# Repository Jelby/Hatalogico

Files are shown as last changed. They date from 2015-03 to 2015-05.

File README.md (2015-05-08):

##Hatalogico
Libraries for the Hatalogico Raspberry Pi Hat

###Cloning This Repo
When cloning, it is crucial that you use the --recursive switch in order to fetch the Adafruit submodules.

All the python files required to drive the I2C chips on the Hatalogico were written and are maintained by [Adafruit Industries](https://www.adafruit.com/). I have simply included them as submodules and written a few examples using them.

Before using these files, you need to setup your Pi for GPIO and I2C (note the Pi 2 has a slightly different method for the latter).

[Setting up the I2C](https://learn.adafruit.com/adafruits-raspberry-pi-lesson-4-gpio-setup/configuring-i2c)

[Setting up the GPIO](https://learn.adafruit.com/adafruits-raspberry-pi-lesson-4-gpio-setup/configuring-gpio)

##Installing
The RPi2 is slightly different but I recommend you 'apt-get' the following packages on both platforms:

**sudo apt-get update -y**  
**sudo apt-get install -y python-dev python-rpi.gpio python-smbus**  
**sudo apt-get install -y i2c-tools libi2c-dev**

You can copy and paste all 3 lines into your terminal and they will run one after the other (synchronously).

You will need to add the I2C tools to both versions:  
**sudo nano /etc/modules**

Scroll to the bottom and add:  
**i2c-dev**

####For RPi B+ and older only:
Also add a new line underneath 'i2c-dev':  
**i2c-bcm2708**

Crtl-X to close, pressing Y to save the changes (overwrite with the same name by pressing enter)

####For the RPi B+ or older you will need to update the blacklist file:  
**sudo nano /etc/modprobe.d/raspi-blacklist.conf**

Update it to read:  
\#blacklist spi-bcm2708  
\#blacklist i2c-bcm2708

After all of this, it's wise to do a little housekeeping (perhaps even removing some unused libraries):  
**sudo apt-get -y purge wolfram-engine**  
**sudo apt-get -y autoremove**  
**sudo apt-get -y clean**  
**sudo apt-get -y update**  
**sudo apt-get -y dist-upgrade**  

#I2C Addresses
(on the prototype model)

1. 16 Channel PWM: **0x70**
2. 4 Channel ADC #1: **0x49**
3. 4 Channel ADC #2: **0x48**
4. Single Channel DAC #1: **0x60**
5. Single Channel DAC #2: **0x61**

###Big thanks to Adafruit without whom the Hatalogico would just be a mug coaster.

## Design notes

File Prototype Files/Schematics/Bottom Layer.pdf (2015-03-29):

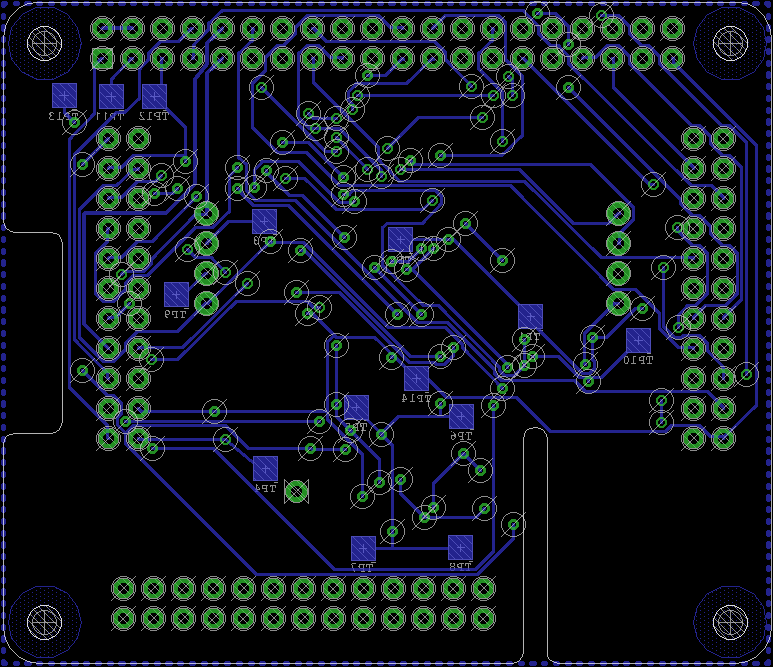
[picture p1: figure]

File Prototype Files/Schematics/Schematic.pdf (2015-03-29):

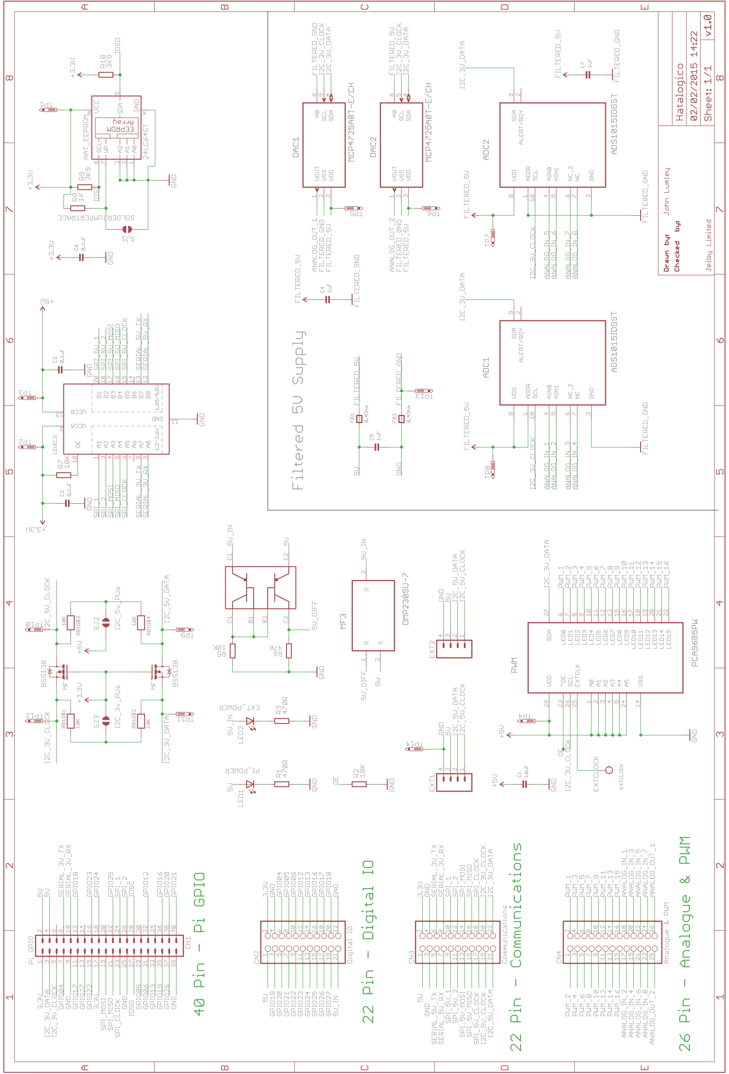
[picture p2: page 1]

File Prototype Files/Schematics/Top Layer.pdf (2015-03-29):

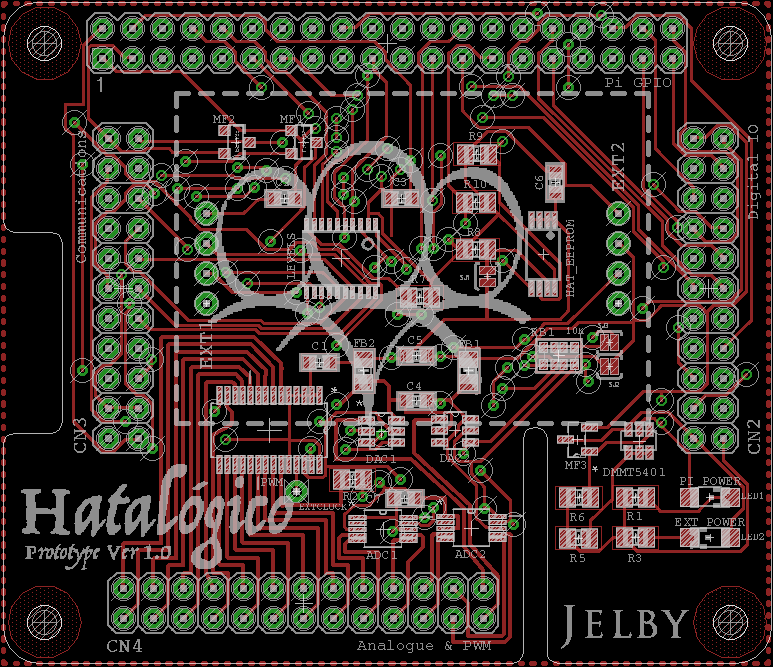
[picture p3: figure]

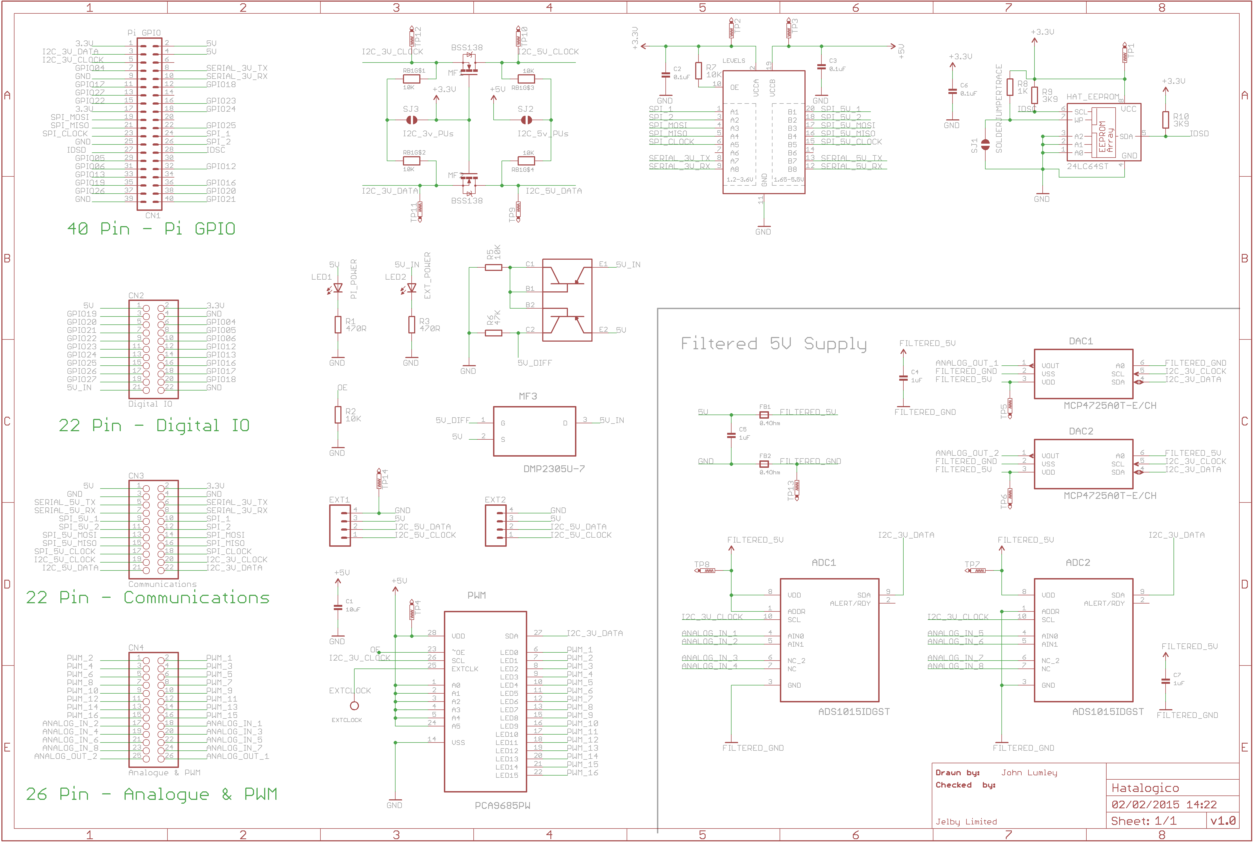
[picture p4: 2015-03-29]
Prototype Files/Schematics/Schematic.tif

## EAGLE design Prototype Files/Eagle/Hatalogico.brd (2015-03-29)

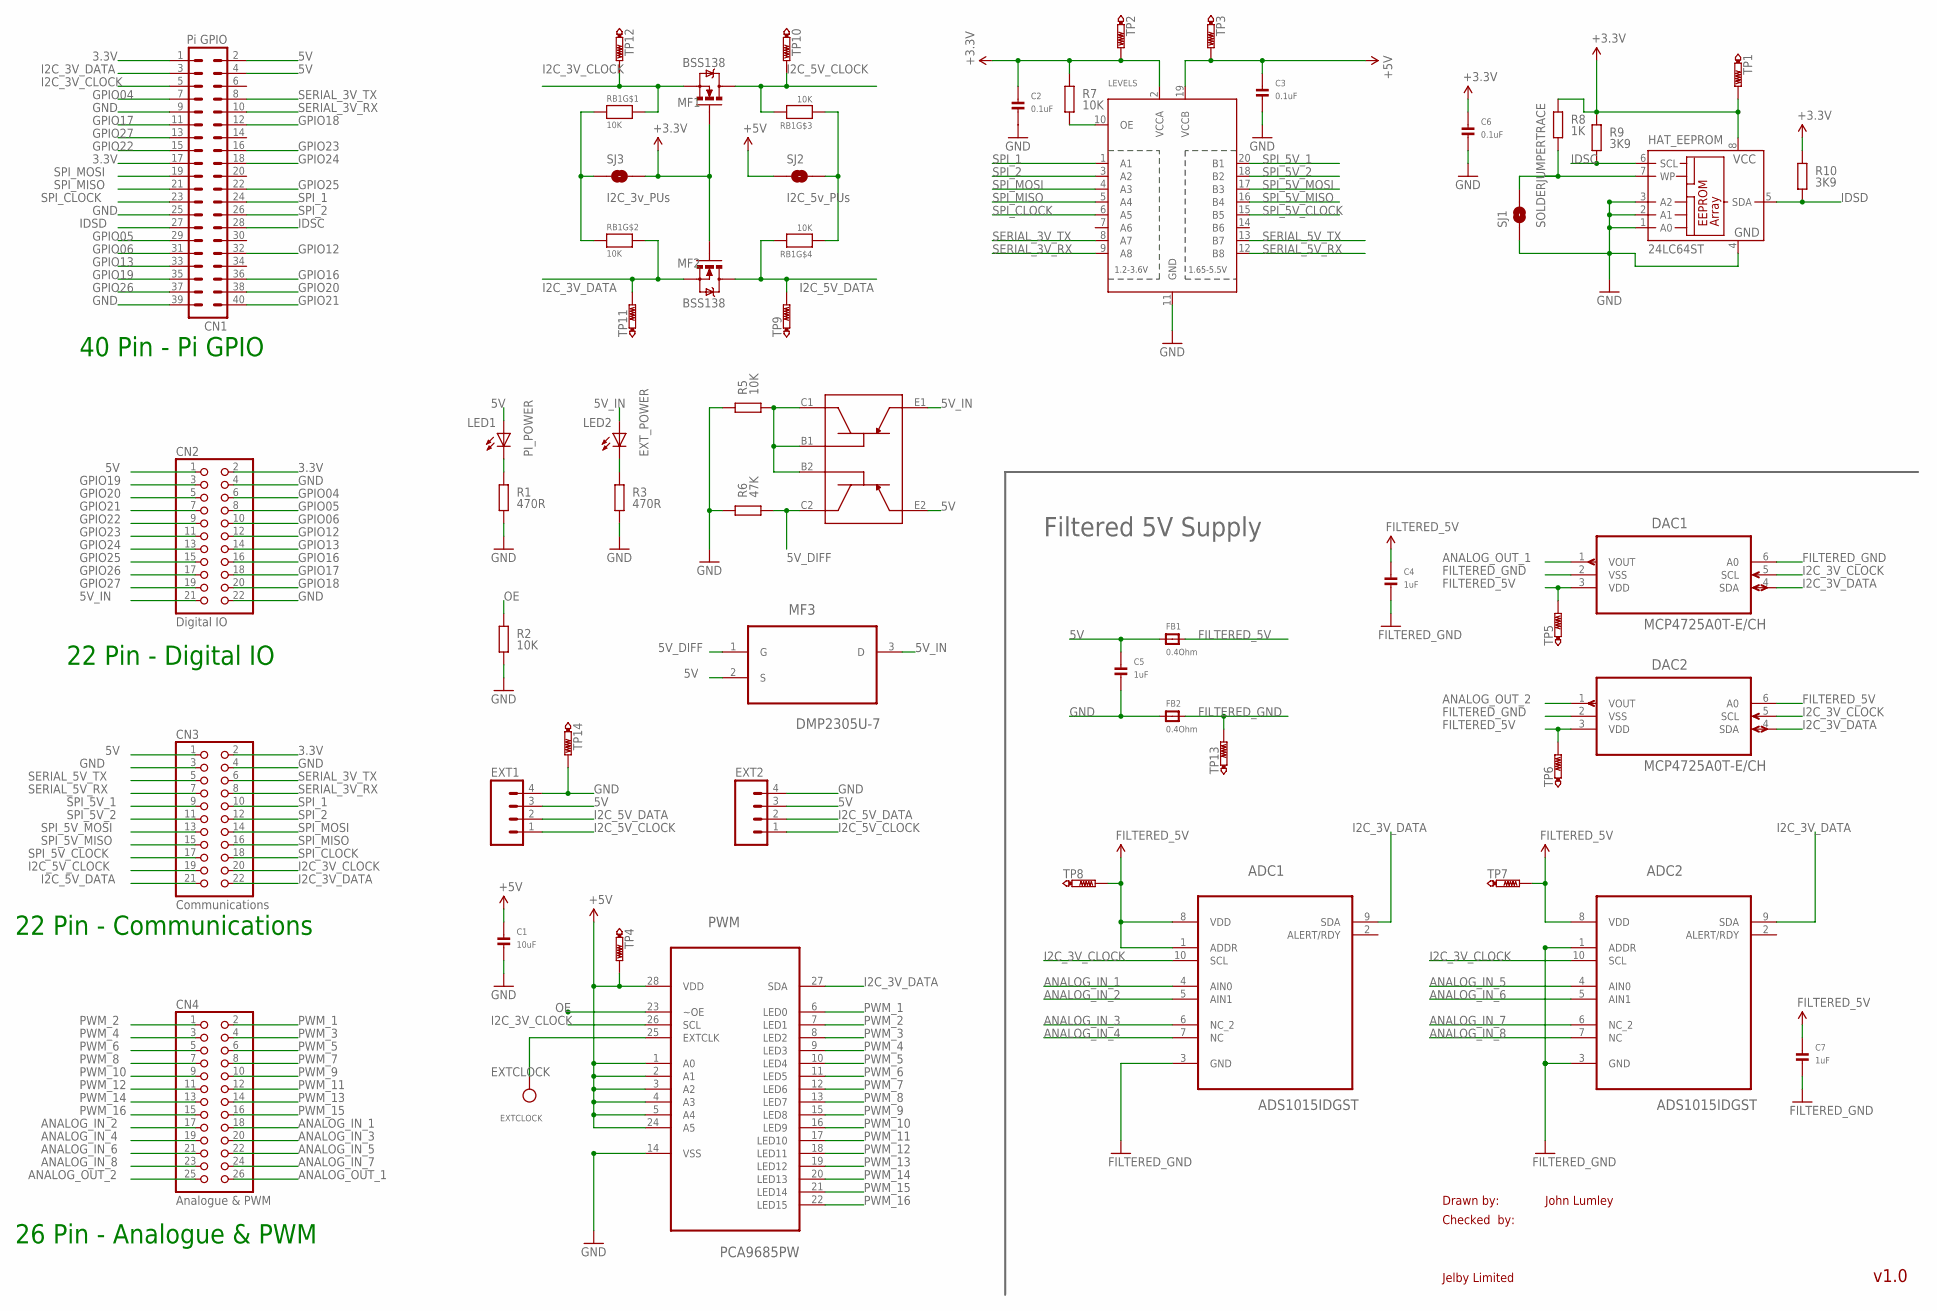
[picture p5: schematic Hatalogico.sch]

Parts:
ADC1, ADC2: ADS1015IDGST; SOP50P490X110-10N
C1: 10uF; 0603
C2, C3, C6: 0.1uF; 0603
C4, C5, C7: 1uF; 0603
CN1: Pi GPIO; PIN_20X2
CN2: Digital IO; 2X11
CN3: Communications; 2X11
CN4: Analogue & PWM; 2X13
DAC1, DAC2: MCP4725A0T-E/CH; SOT95P270X145-6N
EXT1, EXT2: 1X04_HEADER"; 1X04_HEADER
EXTCLOCK: TESTPOINT0.1"; 1X01_ROUND
FB1, FB2: 0.4Ohm; 0805
HAT_EEPROM: 24LC64ST; TSSOP8
LED1: PI_POWER; CHIPLED_1206
LED2: EXT_POWER; CHIPLED_1206
LEVELS: TXB0108PWR; TSSOP20
MF1, MF2: BSS138; SOT23-3
MF3: DMP2305U-7; SOT103P240X110-3N
PWM: PCA9685PW; SOP65P640X110-28N
R1, R3: 470R; M0805; TOLERANCE 5%
R2, R5, R7: 10K; M0805; TOLERANCE 5%
R6: 47K; M0805; TOLERANCE 5%
R8: 1K; M0805; TOLERANCE 5%
R9, R10: 3K9; M0805; TOLERANCE 5%
RB1: 10K; RESPACK_4X0603
SJ1: SOLDERJUMPERTRACE; SJ_2S-TRACE
SJ2: I2C_5v_PUs; PAD-JUMPER-2-NO_YES_SILK
SJ3: I2C_3v_PUs; PAD-JUMPER-2-NO_YES_SILK
T1: DMMT5401
TP1, TP2, TP3, TP4, TP5, TP6, TP7, TP8, TP9, TP10, TP11, TP12, TP13, TP14: PTR1TP20SQ; TP20SQ

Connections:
3.3V: C2.1, C6.1, CN1.1, CN1.17, CN2.2, CN3.2, HAT_EEPROM.8 (VCC), LEVELS.2 (VCCA), MF1.1 (G), MF2.1 (G), R7.2, R8.2, R9.2, R10.2, SJ3.2, TP1.TP, TP2.TP
5V: C1.1, C3.1, C5.1, CN1.2, CN1.4, CN2.1, CN3.1, EXT1.3, EXT2.3, FB1.1, LED1.A, LEVELS.19 (VCCB), MF3.2 (S), PWM.1 (A0), PWM.2 (A1), PWM.3 (A2), PWM.4 (A3), PWM.5 (A4), PWM.24 (A5), PWM.28 (VDD), SJ2.1, T1.E2, TP3.TP, TP4.TP
5V_DIFF: MF3.1 (G), R6.1, T1.C2
5V_IN: CN2.21, LED2.A, MF3.3 (D), T1.E1
ANALOG_IN_1: ADC1.4 (AIN0), CN4.18
ANALOG_IN_2: ADC1.5 (AIN1), CN4.17
ANALOG_IN_3: ADC1.6 (NC_2), CN4.20
ANALOG_IN_4: ADC1.7 (NC), CN4.19
ANALOG_IN_5: ADC2.4 (AIN0), CN4.22
ANALOG_IN_6: ADC2.5 (AIN1), CN4.21
ANALOG_IN_7: ADC2.6 (NC_2), CN4.24
ANALOG_IN_8: ADC2.7 (NC), CN4.23
ANALOG_OUT_1: CN4.26, DAC1.1 (VOUT)
ANALOG_OUT_2: CN4.25, DAC2.1 (VOUT)
EXTCLOCK: EXTCLOCK.1, PWM.25 (EXTCLK)
FILTERED_5V: ADC1.1 (ADDR), ADC1.8 (VDD), ADC2.8 (VDD), C4.1, C7.1, DAC1.3 (VDD), DAC2.3 (VDD), DAC2.6 (A0), FB1.2, TP5.TP, TP6.TP, TP7.TP, TP8.TP
FILTERED_GND: ADC1.3 (GND), ADC2.1 (ADDR), ADC2.3 (GND), C4.2, C7.2, DAC1.2 (VSS), DAC1.6 (A0), DAC2.2 (VSS), FB2.2, TP13.TP
GND: C1.2, C2.2, C3.2, C5.2, C6.2, CN1.9, CN1.25, CN1.39, CN2.4, CN2.22, CN3.3, CN3.4, EXT1.4, EXT2.4, FB2.1, HAT_EEPROM.1 (A0), HAT_EEPROM.2 (A1), HAT_EEPROM.3 (A2), HAT_EEPROM.4 (GND), LEVELS.11 (GND), PWM.14 (VSS), R1.1, R2.1, R3.1, R5.2, R6.2, SJ1.1, TP14.TP
GPIO04: CN1.7, CN2.6
GPIO05: CN1.29, CN2.8
GPIO06: CN1.31, CN2.10
GPIO12: CN1.32, CN2.12
GPIO13: CN1.33, CN2.14
GPIO16: CN1.36, CN2.16
GPIO17: CN1.11, CN2.18
GPIO18: CN1.12, CN2.20
GPIO19: CN1.35, CN2.3
GPIO20: CN1.38, CN2.5
GPIO21: CN1.40, CN2.7
GPIO22: CN1.15, CN2.9
GPIO23: CN1.16, CN2.11
GPIO24: CN1.18, CN2.13
GPIO25: CN1.22, CN2.15
GPIO26: CN1.37, CN2.17
GPIO27: CN1.13, CN2.19
I2C_3V_CLOCK: ADC1.10 (SCL), ADC2.10 (SCL), CN1.5, CN3.20, DAC1.5 (SCL), DAC2.5 (SCL), MF1.2 (S), PWM.26 (SCL), RB1.8 (2), TP12.TP
I2C_3V_DATA: ADC1.9 (SDA), ADC2.9 (SDA), CN1.3, CN3.22, DAC1.4 (SDA), DAC2.4 (SDA), MF2.2 (S), PWM.27 (SDA), RB1.7 (2), TP11.TP
I2C_5V_CLOCK: CN3.19, EXT1.1, EXT2.1, MF1.3 (D), RB1.6 (2), TP10.TP
I2C_5V_DATA: CN3.21, EXT1.2, EXT2.2, MF2.3 (D), RB1.5 (2), TP9.TP
IDSC: CN1.28, HAT_EEPROM.6 (SCL), R9.1
IDSD: CN1.27, HAT_EEPROM.5 (SDA), R10.1
LEDOUT: LED1.C, R1.2
LEDOUT1: LED2.C, R3.2
unnamed: R5.1, T1.B1, T1.B2, T1.C1
unnamed: RB1.1, RB1.2 (1), SJ3.1
unnamed: RB1.3 (1), RB1.4 (1), SJ2.2
unnamed: LEVELS.10 (OE), R7.1
OE: PWM.23 (~OE), R2.2
PWM_1: CN4.2, PWM.6 (LED0)
PWM_2: CN4.1, PWM.7 (LED1)
PWM_3: CN4.4, PWM.8 (LED2)
PWM_4: CN4.3, PWM.9 (LED3)
PWM_5: CN4.6, PWM.10 (LED4)
PWM_6: CN4.5, PWM.11 (LED5)
PWM_7: CN4.8, PWM.12 (LED6)
PWM_8: CN4.7, PWM.13 (LED7)
PWM_9: CN4.10, PWM.15 (LED8)
PWM_10: CN4.9, PWM.16 (LED9)
PWM_11: CN4.12, PWM.17 (LED10)
PWM_12: CN4.11, PWM.18 (LED11)
PWM_13: CN4.14, PWM.19 (LED12)
PWM_14: CN4.13, PWM.20 (LED13)
PWM_15: CN4.16, PWM.21 (LED14)
PWM_16: CN4.15, PWM.22 (LED15)
SERIAL_3V_RX: CN1.10, CN3.8, LEVELS.9 (A8)
SERIAL_3V_TX: CN1.8, CN3.6, LEVELS.8 (A7)
SERIAL_5V_RX: CN3.7, LEVELS.12 (B8)
SERIAL_5V_TX: CN3.5, LEVELS.13 (B7)
SPI_1: CN1.24, CN3.10, LEVELS.1 (A1)
SPI_2: CN1.26, CN3.12, LEVELS.3 (A2)
SPI_5V_1: CN3.9, LEVELS.20 (B1)
SPI_5V_2: CN3.11, LEVELS.18 (B2)
SPI_5V_CLOCK: CN3.17, LEVELS.15 (B5)
SPI_5V_MISO: CN3.15, LEVELS.16 (B4)
SPI_5V_MOSI: CN3.13, LEVELS.17 (B3)
SPI_CLOCK: CN1.23, CN3.18, LEVELS.6 (A5)
SPI_MISO: CN1.21, CN3.16, LEVELS.5 (A4)
SPI_MOSI: CN1.19, CN3.14, LEVELS.4 (A3)
WP: HAT_EEPROM.7 (WP), R8.1, SJ1.2

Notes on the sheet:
Drawn by:
Checked by:
Jelby Limited
John Lumley
v1.0
40 Pin - Pi GPIO
26 Pin - Analogue & PWM
22 Pin - Digital IO
22 Pin - Communications
Filtered 5V Supply

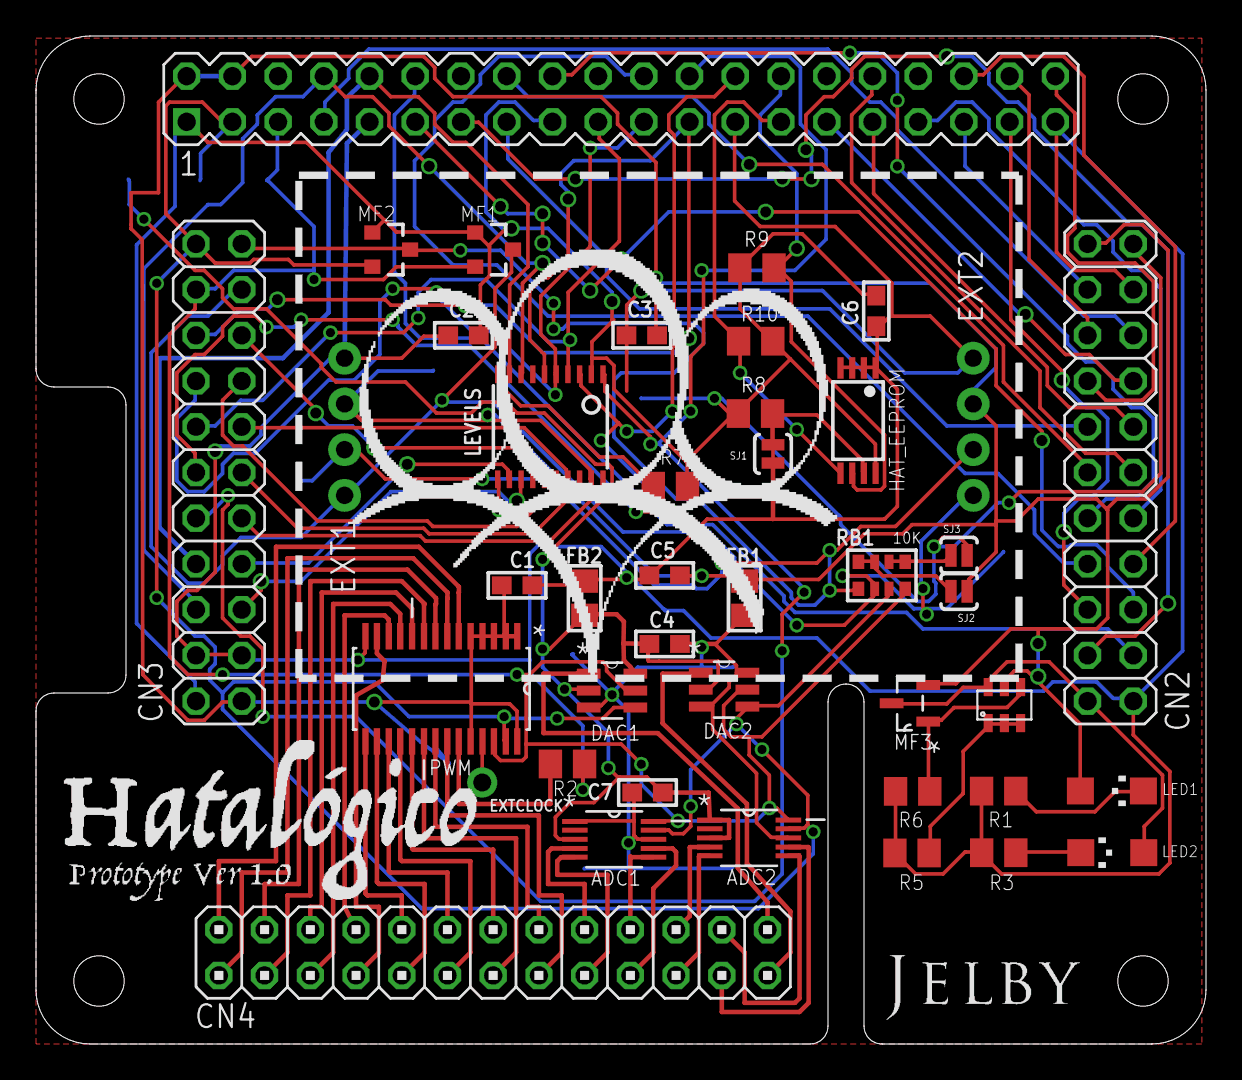
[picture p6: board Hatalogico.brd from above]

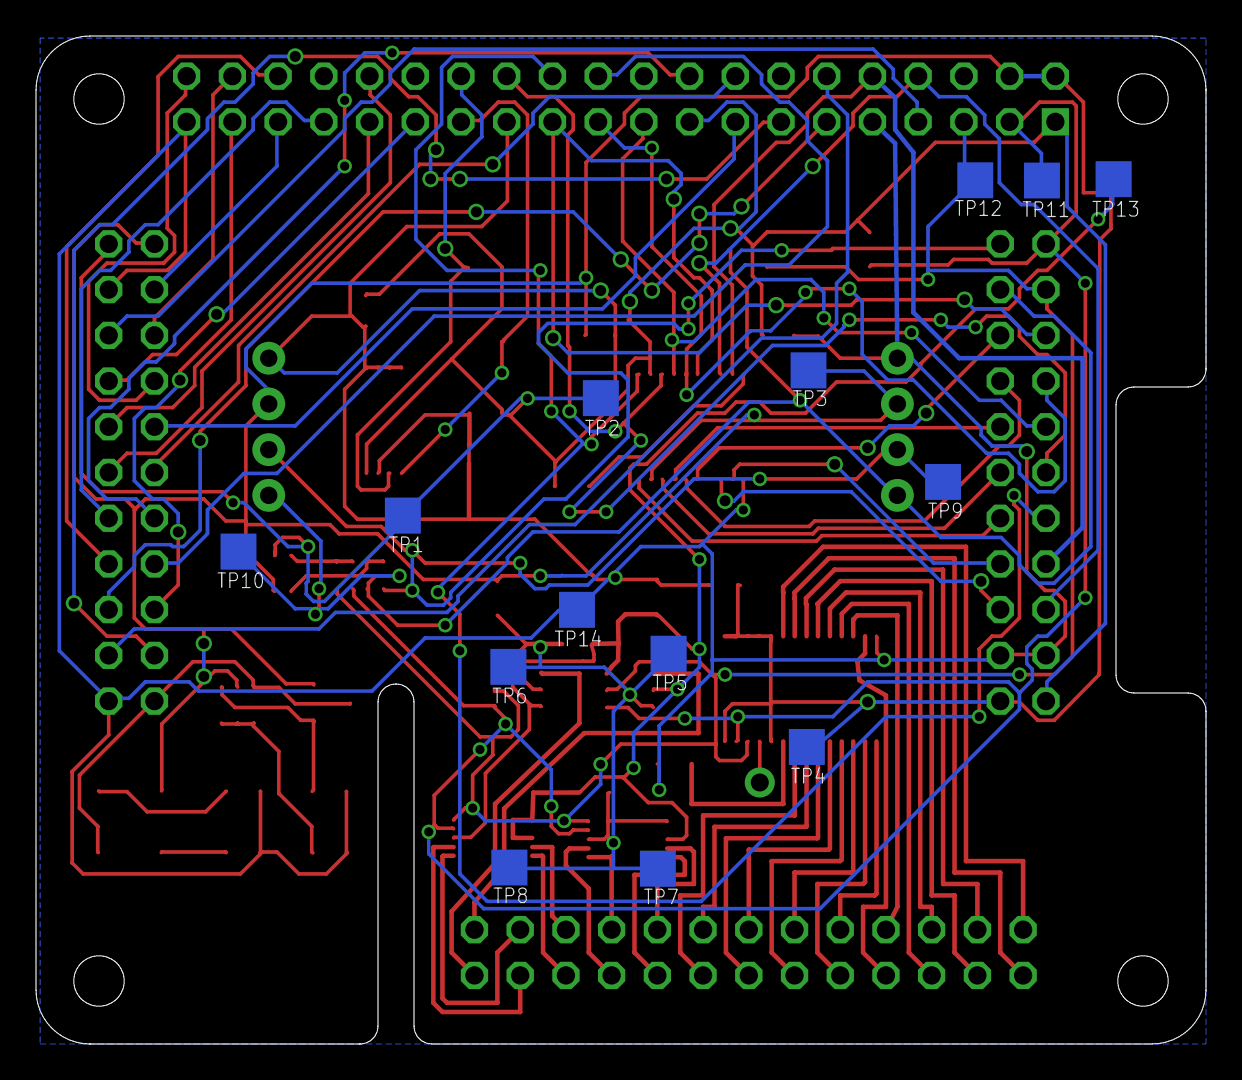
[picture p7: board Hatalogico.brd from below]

Board: 2 copper layers, 65.0 x 56.0 mm, 56 parts (14 on the bottom side), 79 nets.

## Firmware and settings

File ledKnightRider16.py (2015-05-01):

#!/usr/bin/python

# ===========================================================================
# Hatalogico KNIGHT RIDER for 8 LEDs - powered by Adafruit's Libraries
# -------------------------------------------------
# Date: 12/4/2015
# Author: John Lumley
#
# BIG THANKS TO ADAFRUIT INDUSTRIES FOR MAKING THIS POSSIBLE AND EASY
# ===========================================================================

import time, os, sys

# DETERMINE CURRENT PATH
scriptPath = os.path.realpath(os.path.dirname(sys.argv[0]))
os.chdir(scriptPath)
# APPEND FOLDER OF REQUIRED LIBRARY
sys.path.append("Adafruit/Adafruit_PWM_Servo_Driver")
# FINALLY LOAD THE LIBRARY
from Adafruit_PWM_Servo_Driver import PWM

LED_PIN_0 = 0
LED_PIN_1 = 2
LED_PIN_2 = 4
LED_PIN_3 = 6
LED_PIN_4 = 8
LED_PIN_5 = 10
LED_PIN_6 = 12
LED_PIN_7 = 14
LED_PIN_8 = 1
LED_PIN_9 = 3
LED_PIN_10 = 5
LED_PIN_11 = 7
LED_PIN_12 = 9
LED_PIN_13 = 11
LED_PIN_14 = 13
LED_PIN_15 = 15

BRIGHT_0=0
BRIGHT_1=1800
BRIGHT_2=2400
BRIGHT_3=3000
BRIGHT_4=3500
BRIGHT_5=3800
BRIGHT_6=4000
BRIGHT_7=4095

# BUILD 16 ARRAYS OF 8 POSITIONS/VALUES FOR PWM LOOP
position = {} 
position[0] = [ BRIGHT_0, BRIGHT_7, BRIGHT_7, BRIGHT_7, BRIGHT_7, BRIGHT_7, BRIGHT_7, BRIGHT_7, BRIGHT_7, BRIGHT_7, BRIGHT_7, BRIGHT_7, BRIGHT_7, BRIGHT_7, BRIGHT_7, BRIGHT_7 ]
position[1] = [ BRIGHT_1, BRIGHT_0, BRIGHT_7, BRIGHT_7, BRIGHT_7, BRIGHT_7, BRIGHT_7, BRIGHT_7, BRIGHT_7, BRIGHT_7, BRIGHT_7, BRIGHT_7, BRIGHT_7, BRIGHT_7, BRIGHT_7, BRIGHT_7 ]
position[2] = [ BRIGHT_2, BRIGHT_1, BRIGHT_0, BRIGHT_7, BRIGHT_7, BRIGHT_7, BRIGHT_7, BRIGHT_7, BRIGHT_7, BRIGHT_7, BRIGHT_7, BRIGHT_7, BRIGHT_7, BRIGHT_7, BRIGHT_7, BRIGHT_7 ]
position[3] = [ BRIGHT_3, BRIGHT_2, BRIGHT_1, BRIGHT_0, BRIGHT_7, BRIGHT_7, BRIGHT_7, BRIGHT_7, BRIGHT_7, BRIGHT_7, BRIGHT_7, BRIGHT_7, BRIGHT_7, BRIGHT_7, BRIGHT_7, BRIGHT_7 ]
position[4] = [ BRIGHT_4, BRIGHT_3, BRIGHT_2, BRIGHT_1, BRIGHT_0, BRIGHT_7, BRIGHT_7, BRIGHT_7, BRIGHT_7, BRIGHT_7, BRIGHT_7, BRIGHT_7, BRIGHT_7, BRIGHT_7, BRIGHT_7, BRIGHT_7 ]
position[5] = [ BRIGHT_5, BRIGHT_4, BRIGHT_3, BRIGHT_2, BRIGHT_1, BRIGHT_0, BRIGHT_7, BRIGHT_7, BRIGHT_7, BRIGHT_7, BRIGHT_7, BRIGHT_7, BRIGHT_7, BRIGHT_7, BRIGHT_7, BRIGHT_7 ]
position[6] = [ BRIGHT_6, BRIGHT_5, BRIGHT_4, BRIGHT_3, BRIGHT_2, BRIGHT_1, BRIGHT_0, BRIGHT_7, BRIGHT_7, BRIGHT_7, BRIGHT_7, BRIGHT_7, BRIGHT_7, BRIGHT_7, BRIGHT_7, BRIGHT_7 ]
position[7] = [ BRIGHT_7, BRIGHT_6, BRIGHT_5, BRIGHT_4, BRIGHT_3, BRIGHT_2, BRIGHT_1, BRIGHT_0, BRIGHT_7, BRIGHT_7, BRIGHT_7, BRIGHT_7, BRIGHT_7, BRIGHT_7, BRIGHT_7, BRIGHT_7 ]
position[8] = [ BRIGHT_7, BRIGHT_7, BRIGHT_6, BRIGHT_5, BRIGHT_4, BRIGHT_3, BRIGHT_2, BRIGHT_1, BRIGHT_0, BRIGHT_7, BRIGHT_7, BRIGHT_7, BRIGHT_7, BRIGHT_7, BRIGHT_7, BRIGHT_7 ]
position[9] = [ BRIGHT_7, BRIGHT_7, BRIGHT_7, BRIGHT_6, BRIGHT_5, BRIGHT_4, BRIGHT_3, BRIGHT_2, BRIGHT_1, BRIGHT_0, BRIGHT_7, BRIGHT_7, BRIGHT_7, BRIGHT_7, BRIGHT_7, BRIGHT_7 ]
position[10] = [ BRIGHT_7, BRIGHT_7, BRIGHT_7, BRIGHT_7, BRIGHT_6, BRIGHT_5, BRIGHT_4, BRIGHT_3, BRIGHT_2, BRIGHT_1, BRIGHT_0, BRIGHT_7, BRIGHT_7, BRIGHT_7, BRIGHT_7, BRIGHT_7 ]
position[11] = [ BRIGHT_7, BRIGHT_7, BRIGHT_7, BRIGHT_7, BRIGHT_7, BRIGHT_6, BRIGHT_5, BRIGHT_4, BRIGHT_3, BRIGHT_2, BRIGHT_1, BRIGHT_0, BRIGHT_7, BRIGHT_7, BRIGHT_7, BRIGHT_7 ]
position[12] = [ BRIGHT_7, BRIGHT_7, BRIGHT_7, BRIGHT_7, BRIGHT_7, BRIGHT_7, BRIGHT_6, BRIGHT_5, BRIGHT_4, BRIGHT_3, BRIGHT_2, BRIGHT_1, BRIGHT_0, BRIGHT_7, BRIGHT_7, BRIGHT_7 ]
position[13] = [ BRIGHT_7, BRIGHT_7, BRIGHT_7, BRIGHT_7, BRIGHT_7, BRIGHT_7, BRIGHT_7, BRIGHT_6, BRIGHT_5, BRIGHT_4, BRIGHT_3, BRIGHT_2, BRIGHT_1, BRIGHT_0, BRIGHT_7, BRIGHT_7 ]
position[14] = [ BRIGHT_7, BRIGHT_7, BRIGHT_7, BRIGHT_7, BRIGHT_7, BRIGHT_7, BRIGHT_7, BRIGHT_7, BRIGHT_6, BRIGHT_5, BRIGHT_4, BRIGHT_3, BRIGHT_2, BRIGHT_1, BRIGHT_0, BRIGHT_7 ]
position[15] = [ BRIGHT_7, BRIGHT_7, BRIGHT_7, BRIGHT_7, BRIGHT_7, BRIGHT_7, BRIGHT_7, BRIGHT_7, BRIGHT_7, BRIGHT_6, BRIGHT_5, BRIGHT_4, BRIGHT_3, BRIGHT_2, BRIGHT_1, BRIGHT_0 ]
position[16] = [ BRIGHT_7, BRIGHT_7, BRIGHT_7, BRIGHT_7, BRIGHT_7, BRIGHT_7, BRIGHT_7, BRIGHT_7, BRIGHT_7, BRIGHT_7, BRIGHT_6, BRIGHT_5, BRIGHT_4, BRIGHT_3, BRIGHT_2, BRIGHT_0 ]
position[17] = [ BRIGHT_7, BRIGHT_7, BRIGHT_7, BRIGHT_7, BRIGHT_7, BRIGHT_7, BRIGHT_7, BRIGHT_7, BRIGHT_7, BRIGHT_7, BRIGHT_7, BRIGHT_6, BRIGHT_5, BRIGHT_4, BRIGHT_3, BRIGHT_0 ]
position[18] = [ BRIGHT_7, BRIGHT_7, BRIGHT_7, BRIGHT_7, BRIGHT_7, BRIGHT_7, BRIGHT_7, BRIGHT_7, BRIGHT_7, BRIGHT_7, BRIGHT_7, BRIGHT_7, BRIGHT_6, BRIGHT_5, BRIGHT_4, BRIGHT_0 ]
position[19] = [ BRIGHT_7, BRIGHT_7, BRIGHT_7, BRIGHT_7, BRIGHT_7, BRIGHT_7, BRIGHT_7, BRIGHT_7, BRIGHT_7, BRIGHT_7, BRIGHT_7, BRIGHT_7, BRIGHT_7, BRIGHT_6, BRIGHT_5, BRIGHT_0 ]
position[20] = [ BRIGHT_7, BRIGHT_7, BRIGHT_7, BRIGHT_7, BRIGHT_7, BRIGHT_7, BRIGHT_7, BRIGHT_7, BRIGHT_7, BRIGHT_7, BRIGHT_7, BRIGHT_7, BRIGHT_7, BRIGHT_7, BRIGHT_6, BRIGHT_0 ]
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

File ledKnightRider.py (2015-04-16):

#!/usr/bin/python

# ===========================================================================
# Hatalogico KNIGHT RIDER for 8 LEDs - powered by Adafruit's Libraries
# -------------------------------------------------
# Date: 12/4/2015
# Author: John Lumley
#
# BIG THANKS TO ADAFRUIT INDUSTRIES FOR MAKING THIS POSSIBLE AND EASY
# ===========================================================================

import time, os, sys

# DETERMINE CURRENT PATH
scriptPath = os.path.realpath(os.path.dirname(sys.argv[0]))
os.chdir(scriptPath)
# APPEND FOLDER OF REQUIRED LIBRARY
sys.path.append("Adafruit/Adafruit_PWM_Servo_Driver")
# FINALLY LOAD THE LIBRARY
from Adafruit_PWM_Servo_Driver import PWM

LED_PIN_0 = 1
LED_PIN_1 = 3
LED_PIN_2 = 5
LED_PIN_3 = 7
LED_PIN_4 = 9
LED_PIN_5 = 11
LED_PIN_6 = 13
LED_PIN_7 = 15

BRIGHT_STEP_0=0
BRIGHT_STEP_1=2048
BRIGHT_STEP_2=3070
BRIGHT_STEP_3=3500
BRIGHT_STEP_4=3800
BRIGHT_STEP_5=4048
BRIGHT_STEP_6=4095
BRIGHT_STEP_7=4095

# BUILD 16 ARRAYS OF 8 POSITIONS/VALUES FOR PWM LOOP
position = {} 
position[0] = [ BRIGHT_STEP_0, BRIGHT_STEP_5, BRIGHT_STEP_6, BRIGHT_STEP_7, BRIGHT_STEP_7, BRIGHT_STEP_7, BRIGHT_STEP_7, BRIGHT_STEP_7 ]
position[1] = [ BRIGHT_STEP_0, BRIGHT_STEP_4, BRIGHT_STEP_5, BRIGHT_STEP_6, BRIGHT_STEP_7, BRIGHT_STEP_7, BRIGHT_STEP_7, BRIGHT_STEP_7 ]
position[2] = [ BRIGHT_STEP_0, BRIGHT_STEP_3, BRIGHT_STEP_4, BRIGHT_STEP_5, BRIGHT_STEP_6, BRIGHT_STEP_7, BRIGHT_STEP_7, BRIGHT_STEP_7 ]
position[3] = [ BRIGHT_STEP_0, BRIGHT_STEP_2, BRIGHT_STEP_3, BRIGHT_STEP_4, BRIGHT_STEP_5, BRIGHT_STEP_6, BRIGHT_STEP_7, BRIGHT_STEP_7 ]
position[4] = [ BRIGHT_STEP_0, BRIGHT_STEP_1, BRIGHT_STEP_2, BRIGHT_STEP_3, BRIGHT_STEP_4, BRIGHT_STEP_5, BRIGHT_STEP_6, BRIGHT_STEP_7 ]
position[5] = [ BRIGHT_STEP_1, BRIGHT_STEP_0, BRIGHT_STEP_1, BRIGHT_STEP_2, BRIGHT_STEP_3, BRIGHT_STEP_4, BRIGHT_STEP_5, BRIGHT_STEP_6 ]
position[6] = [ BRIGHT_STEP_2, BRIGHT_STEP_1, BRIGHT_STEP_0, BRIGHT_STEP_1, BRIGHT_STEP_2, BRIGHT_STEP_3, BRIGHT_STEP_4, BRIGHT_STEP_5 ]
position[7] = [ BRIGHT_STEP_3, BRIGHT_STEP_2, BRIGHT_STEP_1, BRIGHT_STEP_0, BRIGHT_STEP_1, BRIGHT_STEP_2, BRIGHT_STEP_3, BRIGHT_STEP_4 ]
position[8] = [ BRIGHT_STEP_4, BRIGHT_STEP_3, BRIGHT_STEP_2, BRIGHT_STEP_1, BRIGHT_STEP_0, BRIGHT_STEP_1, BRIGHT_STEP_2, BRIGHT_STEP_3 ]
position[9] = [ BRIGHT_STEP_5, BRIGHT_STEP_4, BRIGHT_STEP_3, BRIGHT_STEP_2, BRIGHT_STEP_1, BRIGHT_STEP_0, BRIGHT_STEP_1, BRIGHT_STEP_2 ]
position[10] = [ BRIGHT_STEP_6, BRIGHT_STEP_5, BRIGHT_STEP_4, BRIGHT_STEP_3, BRIGHT_STEP_2, BRIGHT_STEP_1, BRIGHT_STEP_0, BRIGHT_STEP_1 ]
position[11] = [ BRIGHT_STEP_7, BRIGHT_STEP_6, BRIGHT_STEP_5, BRIGHT_STEP_4, BRIGHT_STEP_3, BRIGHT_STEP_2, BRIGHT_STEP_1, BRIGHT_STEP_0 ]
position[12] = [ BRIGHT_STEP_7, BRIGHT_STEP_7, BRIGHT_STEP_6, BRIGHT_STEP_5, BRIGHT_STEP_4, BRIGHT_STEP_3, BRIGHT_STEP_2, BRIGHT_STEP_0 ]
position[13] = [ BRIGHT_STEP_7, BRIGHT_STEP_7, BRIGHT_STEP_7, BRIGHT_STEP_6, BRIGHT_STEP_5, BRIGHT_STEP_4, BRIGHT_STEP_3, BRIGHT_STEP_0 ]
position[14] = [ BRIGHT_STEP_7, BRIGHT_STEP_7, BRIGHT_STEP_7, BRIGHT_STEP_7, BRIGHT_STEP_6, BRIGHT_STEP_5, BRIGHT_STEP_4, BRIGHT_STEP_0 ]
position[15] = [ BRIGHT_STEP_7, BRIGHT_STEP_7, BRIGHT_STEP_7, BRIGHT_STEP_7, BRIGHT_STEP_7, BRIGHT_STEP_6, BRIGHT_STEP_5, BRIGHT_STEP_0 ]

# SETUP THE PWM DRIVER (I2C ADDRESS IS 70 BY DEFAULT ON HATALOGICO)
# EACH CHANNEL RANGES FROM 0 (off) TO 4095 (on)
pwm = PWM(0x70)
# SET FREQUENCY
pwm.setPWMFreq(120)

while (True):
	for posNo in range(0, 16, +1):
		pwm.setPWM(LED_PIN_0, 0, position[ posNo ][0])
		pwm.setPWM(LED_PIN_1, 0, position[ posNo ][1])
		pwm.setPWM(LED_PIN_2, 0, position[ posNo ][2])
		pwm.setPWM(LED_PIN_3, 0, position[ posNo ][3])
		pwm.setPWM(LED_PIN_4, 0, position[ posNo ][4])
		pwm.setPWM(LED_PIN_5, 0, position[ posNo ][5])
		pwm.setPWM(LED_PIN_6, 0, position[ posNo ][6])
		pwm.setPWM(LED_PIN_7, 0, position[ posNo ][7])
		
		# HAVE A LITTLE NAP
		time.sleep(0.05)

	for posNo in range(15, -1, -1):
		pwm.setPWM(LED_PIN_0, 0, position[ posNo ][0])
		pwm.setPWM(LED_PIN_1, 0, position[ posNo ][1])
		pwm.setPWM(LED_PIN_2, 0, position[ posNo ][2])
		pwm.setPWM(LED_PIN_3, 0, position[ posNo ][3])
		pwm.setPWM(LED_PIN_4, 0, position[ posNo ][4])
		pwm.setPWM(LED_PIN_5, 0, position[ posNo ][5])
		pwm.setPWM(LED_PIN_6, 0, position[ posNo ][6])
		pwm.setPWM(LED_PIN_7, 0, position[ posNo ][7])
		
		# HAVE A LITTLE NAP
		time.sleep(0.05)

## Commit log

2015-03-22 Adding first examples
    LED PWM example
    DAC to ADC example
2015-03-24 Updating LED examples
    And a startup test script
2015-03-24 Adding I2C addesses
2015-03-29 Schematics and design files
    [Hatalogico.brd, Hatalogico.sch]
2015-04-12 Random LED timing tweak
2015-04-13 Reverse KR brightnesses for sinking not sourcing
    [ledKnightRider.py]

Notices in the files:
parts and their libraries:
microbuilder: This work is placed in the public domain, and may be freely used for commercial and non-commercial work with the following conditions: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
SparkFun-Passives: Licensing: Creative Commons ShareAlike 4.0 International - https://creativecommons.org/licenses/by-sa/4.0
